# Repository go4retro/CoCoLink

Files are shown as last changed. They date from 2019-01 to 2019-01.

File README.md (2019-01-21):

# CoCoLink - A TANDY Color Computer RS-232 Pak Work-alike with High Speed mods and Sockmaster mods
This cartridge reproduces the functionality of the TANDY Color Computer RS-232 Pak with some performance enchancements.

## Enhancements
* Up to 4 cards are supported in a system ($ff68,$ff6c,$ff7x,$ff7c)
* Supports additional, faster bps rates, including 57,600 bps, 115,200 bps, and 230,400 bps
* Includes support for some of Sockmaster's [mods](http://users.axess.com/twilight/sock/rs232.html "mods"), including:
  * Swappable DCD and DSR lines
  * Auto-RTS (incomplete support at present)

## License
Copyright (C) 2018  RETRO Innovations

These files are free designs; you can redistribute them and/or modify
them under the terms of the Creative Commons Attribution-ShareAlike 
4.0 International License.

You should have received a copy of the license along with this
work. If not, see <http://creativecommons.org/licenses/by-sa/4.0/>.

These files are distributed in the hope that they will be useful,
but WITHOUT ANY WARRANTY; without even the implied warranty of
MERCHANTABILITY or FITNESS FOR A PARTICULAR PURPOSE.  See the
license for more details.

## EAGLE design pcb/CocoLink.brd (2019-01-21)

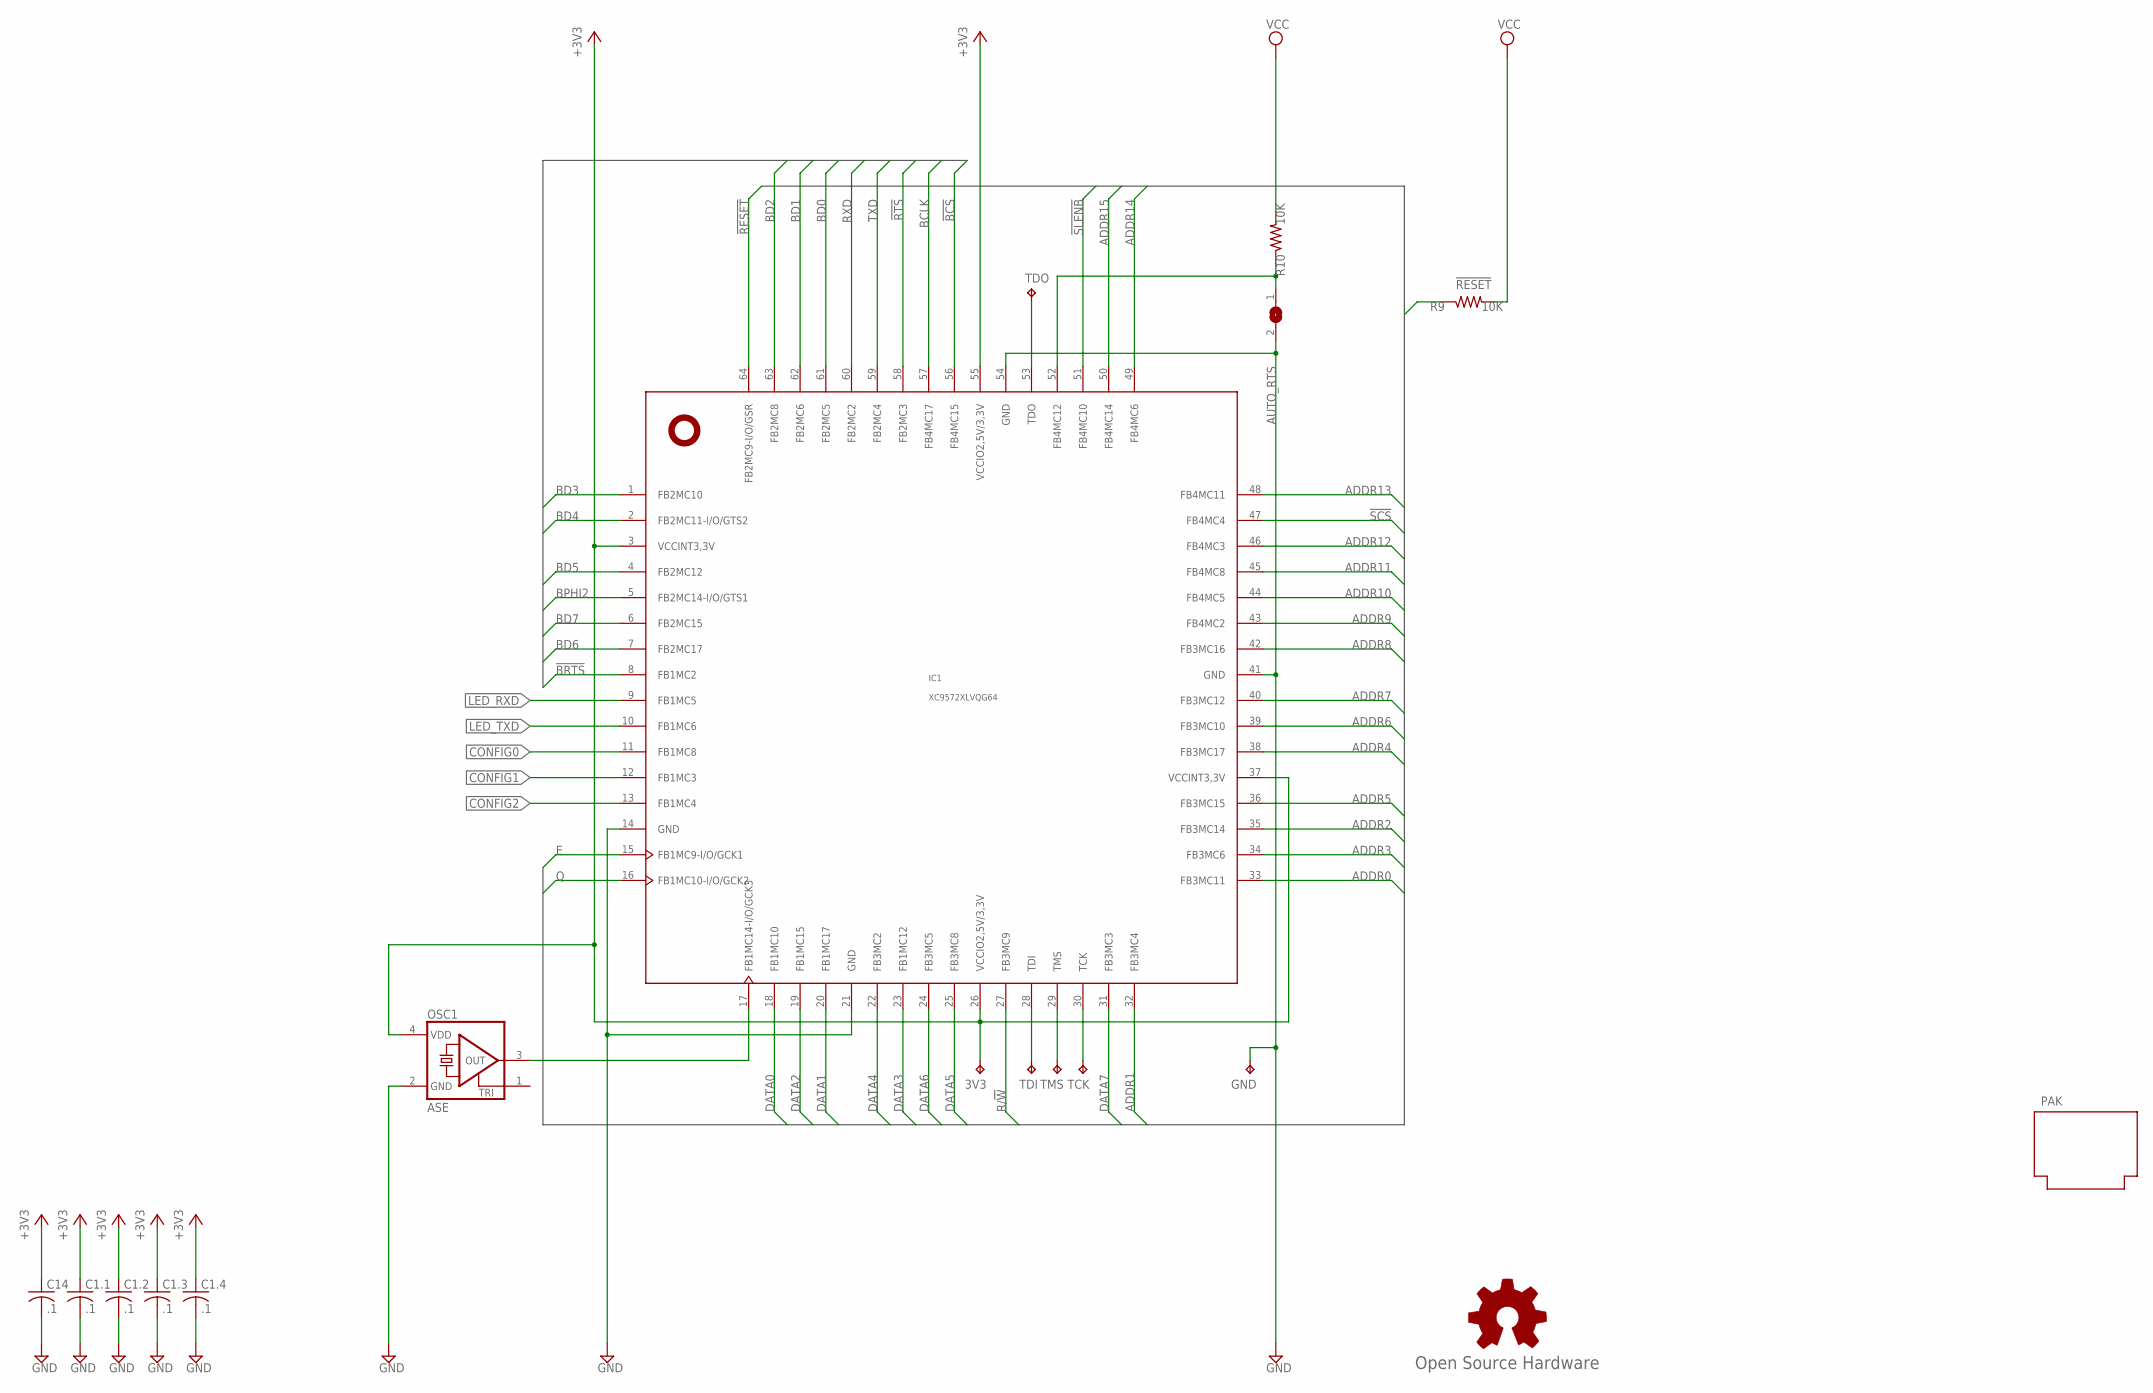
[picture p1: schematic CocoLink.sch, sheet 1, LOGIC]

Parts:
3V3: TPTP10R; TP10R
AUTO_RTS: SJ
C1.1, C1.2, C1.3, C1.4, C14: .1; C0402
GND: TPTP10R; TP10R
GOLD_ORB_SM1: Open Source Hardware; OSHW_8MM
IC1: XC9572XLVQG64; VQFP64
OSC1: ASE
PAK: PROGRAM_PAK
R9, R10: 10K; R0402
TCK: TPTP10R; TP10R
TDI: TPTP10R; TP10R
TDO: TPTP10R; TP10R
TMS: TPTP10R; TP10R

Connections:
!BCS: IC1.56 (FB4MC15); also elsewhere on the board
!BRTS: IC1.8 (FB1MC2); also elsewhere on the board
!RESET: IC1.64 (FB2MC9-I/O/GSR), R9.1; also elsewhere on the board
!RTS: IC1.58 (FB2MC3); also elsewhere on the board
!SCS: IC1.47 (FB4MC4); also elsewhere on the board
!SLENB: IC1.51 (FB4MC10); also elsewhere on the board
+3V3: 3V3.TP, C1.1.1, C1.2.1, C1.3.1, C1.4.1, C14.1, IC1.3 (VCCINT3,3V), IC1.26 (VCCIO2,5V/3,3V), IC1.37 (VCCINT3,3V), IC1.55 (VCCIO2,5V/3,3V), OSC1.4 (VDD); also elsewhere on the board
ADDR0: IC1.33 (FB3MC11); also elsewhere on the board
ADDR1: IC1.32 (FB3MC4); also elsewhere on the board
ADDR2: IC1.35 (FB3MC14); also elsewhere on the board
ADDR3: IC1.34 (FB3MC6); also elsewhere on the board
ADDR4: IC1.38 (FB3MC17); also elsewhere on the board
ADDR5: IC1.36 (FB3MC15); also elsewhere on the board
ADDR6: IC1.39 (FB3MC10); also elsewhere on the board
ADDR7: IC1.40 (FB3MC12); also elsewhere on the board
ADDR8: IC1.42 (FB3MC16); also elsewhere on the board
ADDR9: IC1.43 (FB4MC2); also elsewhere on the board
ADDR10: IC1.44 (FB4MC5); also elsewhere on the board
ADDR11: IC1.45 (FB4MC8); also elsewhere on the board
ADDR12: IC1.46 (FB4MC3); also elsewhere on the board
ADDR13: IC1.48 (FB4MC11); also elsewhere on the board
ADDR14: IC1.49 (FB4MC6); also elsewhere on the board
ADDR15: IC1.50 (FB4MC14); also elsewhere on the board
BCLK: IC1.57 (FB4MC17); also elsewhere on the board
BD0: IC1.61 (FB2MC5); also elsewhere on the board
BD1: IC1.62 (FB2MC6); also elsewhere on the board
BD2: IC1.63 (FB2MC8); also elsewhere on the board
BD3: IC1.1 (FB2MC10); also elsewhere on the board
BD4: IC1.2 (FB2MC11-I/O/GTS2); also elsewhere on the board
BD5: IC1.4 (FB2MC12); also elsewhere on the board
BD6: IC1.7 (FB2MC17); also elsewhere on the board
BD7: IC1.6 (FB2MC15); also elsewhere on the board
BPHI2: IC1.5 (FB2MC14-I/O/GTS1); also elsewhere on the board
CONFIG0: IC1.11 (FB1MC8); also elsewhere on the board
CONFIG1: IC1.12 (FB1MC3); also elsewhere on the board
CONFIG2: IC1.13 (FB1MC4); also elsewhere on the board
DATA0: IC1.18 (FB1MC10); also elsewhere on the board
DATA1: IC1.20 (FB1MC17); also elsewhere on the board
DATA2: IC1.19 (FB1MC15); also elsewhere on the board
DATA3: IC1.23 (FB1MC12); also elsewhere on the board
DATA4: IC1.22 (FB3MC2); also elsewhere on the board
DATA5: IC1.25 (FB3MC8); also elsewhere on the board
DATA6: IC1.24 (FB3MC5); also elsewhere on the board
DATA7: IC1.31 (FB3MC3); also elsewhere on the board
E: IC1.15 (FB1MC9-I/O/GCK1); also elsewhere on the board
GND: AUTO_RTS.2, C1.1.2, C1.2.2, C1.3.2, C1.4.2, C14.2, GND.TP, IC1.14 (GND), IC1.21 (GND), IC1.41 (GND), IC1.54 (GND), OSC1.2 (GND); also elsewhere on the board
LED_RXD: IC1.9 (FB1MC5); also elsewhere on the board
LED_TXD: IC1.10 (FB1MC6); also elsewhere on the board
unnamed: IC1.53 (TDO), TDO.TP
unnamed: IC1.28 (TDI), TDI.TP
unnamed: IC1.29 (TMS), TMS.TP
unnamed: IC1.30 (TCK), TCK.TP
unnamed: IC1.17 (FB1MC14-I/O/GCK3), OSC1.3 (OUT)
unnamed: AUTO_RTS.1, IC1.52 (FB4MC12), R10.1
Q: IC1.16 (FB1MC10-I/O/GCK2); also elsewhere on the board
R/!W: IC1.27 (FB3MC9); also elsewhere on the board
RXD: IC1.60 (FB2MC2); also elsewhere on the board
TXD: IC1.59 (FB2MC4); also elsewhere on the board
VCC: R9.2, R10.2; also elsewhere on the board

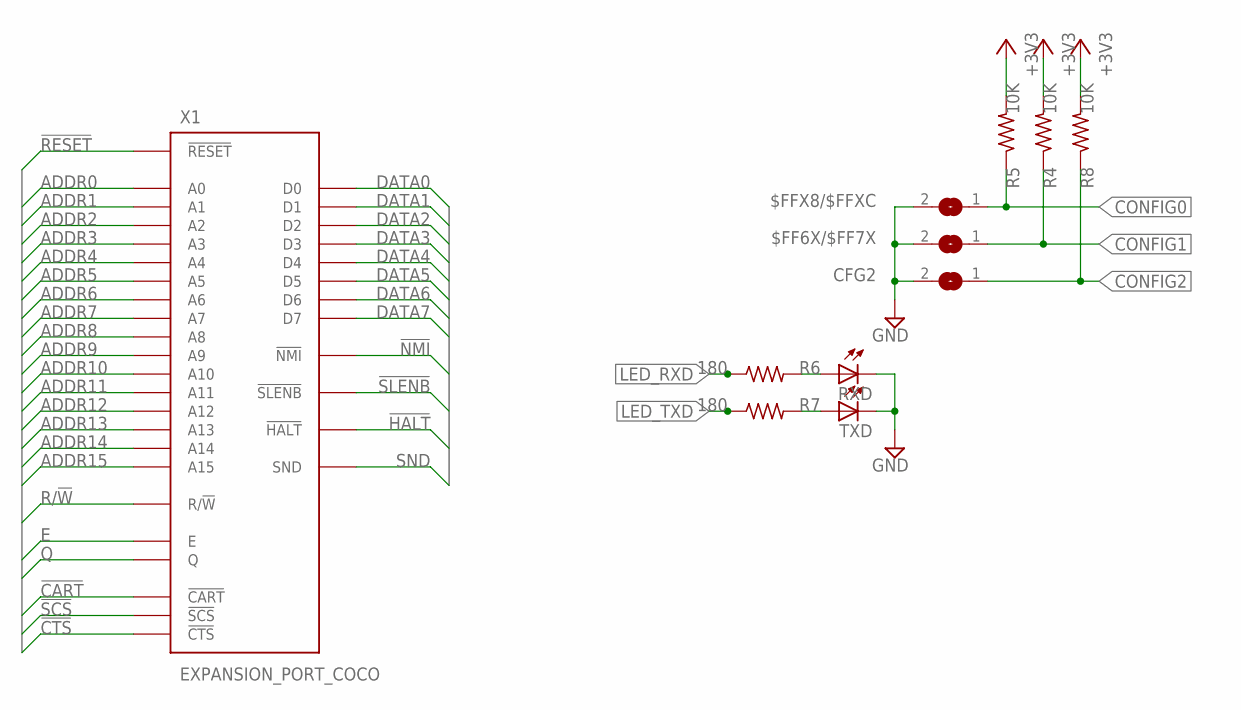
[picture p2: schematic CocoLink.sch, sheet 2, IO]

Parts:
$FF6X/$FF7X: SJ
$FFX8/$FFXC: SJ
CFG2: SJ
R4, R5, R8: 10K; R0402
R6, R7: 180; R0402
RXD: LED3MM
TXD: LED3MM
X1: EXPANSION_PORT_COCO; MA20-2

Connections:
!CART: X1.8 (!CART); also elsewhere on the board
!CTS: X1.32 (!CTS)
!HALT: X1.3 (!HALT)
!NMI: X1.4 (!NMI)
!RESET: X1.5 (!RESET); also elsewhere on the board
!SCS: X1.36 (!SCS); also elsewhere on the board
!SLENB: X1.40 (!SLENB); also elsewhere on the board
+3V3: R4.2, R5.2, R8.2; also elsewhere on the board
+12V: X1.2 (+12V)
-12V: X1.1 (-12V)
ADDR0: X1.19 (A0); also elsewhere on the board
ADDR1: X1.20 (A1); also elsewhere on the board
ADDR2: X1.21 (A2); also elsewhere on the board
ADDR3: X1.22 (A3); also elsewhere on the board
ADDR4: X1.23 (A4); also elsewhere on the board
ADDR5: X1.24 (A5); also elsewhere on the board
ADDR6: X1.25 (A6); also elsewhere on the board
ADDR7: X1.26 (A7); also elsewhere on the board
ADDR8: X1.27 (A8); also elsewhere on the board
ADDR9: X1.28 (A9); also elsewhere on the board
ADDR10: X1.29 (A10); also elsewhere on the board
ADDR11: X1.30 (A11); also elsewhere on the board
ADDR12: X1.31 (A12); also elsewhere on the board
ADDR13: X1.37 (A13); also elsewhere on the board
ADDR14: X1.38 (A14); also elsewhere on the board
ADDR15: X1.39 (A15); also elsewhere on the board
CONFIG0: $FFX8/$FFXC.1, R5.1; also elsewhere on the board
CONFIG1: $FF6X/$FF7X.1, R4.1; also elsewhere on the board
CONFIG2: CFG2.1, R8.1; also elsewhere on the board
DATA0: X1.10 (D0); also elsewhere on the board
DATA1: X1.11 (D1); also elsewhere on the board
DATA2: X1.12 (D2); also elsewhere on the board
DATA3: X1.13 (D3); also elsewhere on the board
DATA4: X1.14 (D4); also elsewhere on the board
DATA5: X1.15 (D5); also elsewhere on the board
DATA6: X1.16 (D6); also elsewhere on the board
DATA7: X1.17 (D7); also elsewhere on the board
E: X1.6 (E); also elsewhere on the board
GND: $FF6X/$FF7X.2, $FFX8/$FFXC.2, CFG2.2, RXD.K (C), TXD.K (C), X1.33 (GND), X1.34 (GND); also elsewhere on the board
LED_RXD: R6.1; also elsewhere on the board
LED_TXD: R7.1; also elsewhere on the board
unnamed: R7.2, TXD.A
unnamed: R6.2, RXD.A
Q: X1.7 (Q); also elsewhere on the board
R/!W: X1.18 (R/!W); also elsewhere on the board
SND: X1.35 (SND)
VCC: X1.9 (VCC); also elsewhere on the board

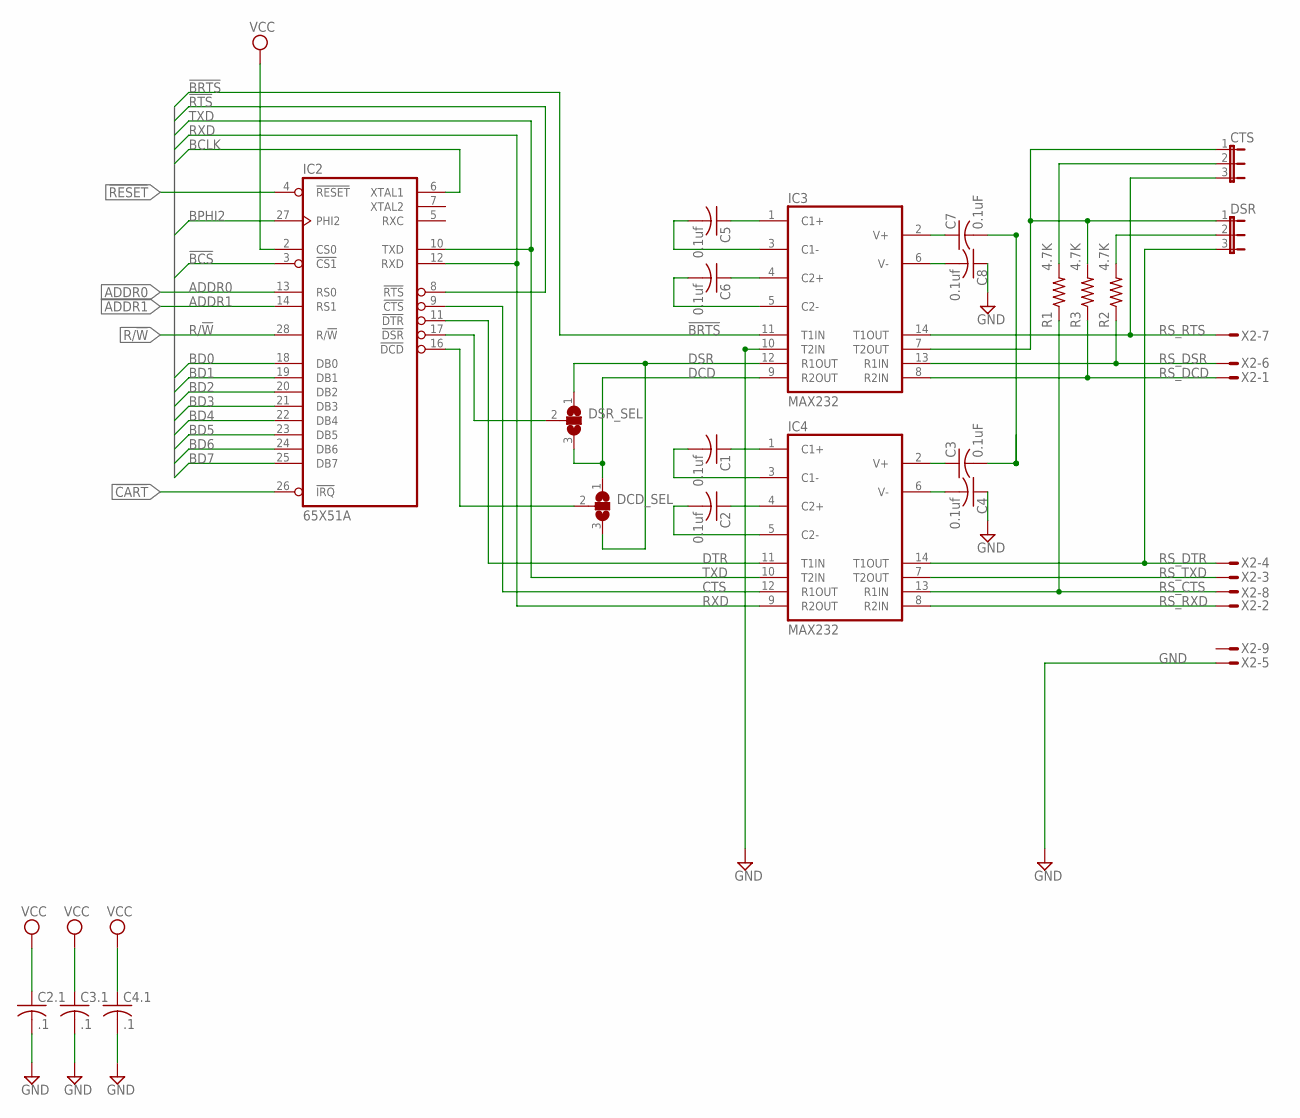
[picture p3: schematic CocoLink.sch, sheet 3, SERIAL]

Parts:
C1, C2, C4, C5, C6, C8: 0.1uf; C0402
C2.1, C3.1, C4.1: .1; C0402
C3, C7: 0.1uF; C0402
CTS: JP2E; JP2
DCD_SEL: SJ2W; SJ_2
DSR: JP2E; JP2
DSR_SEL: SJ2W; SJ_2
IC2: 65X51A; DIL28-ROUNDPAD
IC3, IC4: MAX232; SO16
R1, R2, R3: 4.7K; R1206
X2: M09DS; M09D

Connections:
!BCS: IC2.3 (!CS1); also elsewhere on the board
!BRTS: IC3.11 (T1IN); also elsewhere on the board
!CART: IC2.26 (!IRQ); also elsewhere on the board
!RESET: IC2.4 (!RESET); also elsewhere on the board
!RTS: IC2.8 (!RTS); also elsewhere on the board
ACIA_DCD: DCD_SEL.2, IC2.16 (!DCD)
ACIA_DSR: DSR_SEL.2, IC2.17 (!DSR)
ADDR0: IC2.13 (RS0); also elsewhere on the board
ADDR1: IC2.14 (RS1); also elsewhere on the board
BCLK: IC2.6 (XTAL1); also elsewhere on the board
BD0: IC2.18 (DB0); also elsewhere on the board
BD1: IC2.19 (DB1); also elsewhere on the board
BD2: IC2.20 (DB2); also elsewhere on the board
BD3: IC2.21 (DB3); also elsewhere on the board
BD4: IC2.22 (DB4); also elsewhere on the board
BD5: IC2.23 (DB5); also elsewhere on the board
BD6: IC2.24 (DB6); also elsewhere on the board
BD7: IC2.25 (DB7); also elsewhere on the board
BPHI2: IC2.27 (PHI2); also elsewhere on the board
CTS: IC2.9 (!CTS), IC4.12 (R1OUT)
DCD: DCD_SEL.1, DSR_SEL.3, IC3.9 (R2OUT)
DSR: DCD_SEL.3, DSR_SEL.1, IC3.12 (R1OUT)
DTR: IC2.11 (!DTR), IC4.11 (T1IN)
GND: C2.1.2, C3.1.2, C4.1, C4.1.2, C8.1, IC2.1 (GND), IC3.10 (T2IN), IC3.15 (GND), IC4.15 (GND), X2.5; also elsewhere on the board
unnamed: DSR.2, R2.2
unnamed: CTS.1, DSR.1, IC3.7 (T2OUT), R3.2
unnamed: CTS.2, R1.2
unnamed: C1.1, IC4.1 (C1+)
unnamed: C1.2, IC4.3 (C1-)
unnamed: C2.1, IC4.4 (C2+)
unnamed: C2.2, IC4.5 (C2-)
unnamed: C3.1, IC4.2 (V+)
unnamed: C4.2, IC4.6 (V-)
unnamed: C5.1, IC3.1 (C1+)
unnamed: C5.2, IC3.3 (C1-)
unnamed: C6.1, IC3.4 (C2+)
unnamed: C6.2, IC3.5 (C2-)
unnamed: C7.1, IC3.2 (V+)
unnamed: C8.2, IC3.6 (V-)
R/!W: IC2.28 (R/!W); also elsewhere on the board
RS_CTS: IC4.13 (R1IN), R1.1, X2.8
RS_DCD: IC3.13 (R1IN), R2.1, X2.6
RS_DSR: IC3.8 (R2IN), R3.1, X2.1
RS_DTR: DSR.3, IC4.14 (T1OUT), X2.4
RS_RTS: CTS.3, IC3.14 (T1OUT), X2.7
RS_RXD: IC4.8 (R2IN), X2.2
RS_TXD: IC4.7 (T2OUT), X2.3
RXD: IC2.12 (RXD), IC4.9 (R2OUT); also elsewhere on the board
TXD: IC2.10 (TXD), IC4.10 (T2IN); also elsewhere on the board
VCC: C2.1.1, C3.2, C3.1.1, C4.1.1, C7.2, IC2.2 (CS0), IC2.15 (VCC), IC3.16 (VCC), IC4.16 (VCC); also elsewhere on the board

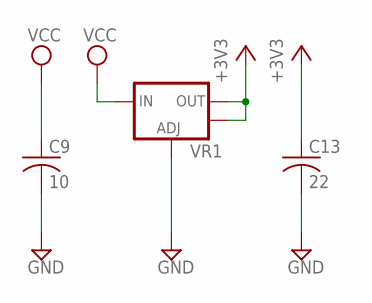
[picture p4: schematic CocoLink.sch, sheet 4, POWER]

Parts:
C9: 10; C0805
C13: 22; C0805
VR1: V_REG_LM1117SOT223; SOT223

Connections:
+3V3: C13.1, VR1.2 (OUT), VR1.4 (OUT); also elsewhere on the board
GND: C9.2, C13.2, VR1.1 (ADJ); also elsewhere on the board
VCC: C9.1, VR1.3 (IN); also elsewhere on the board

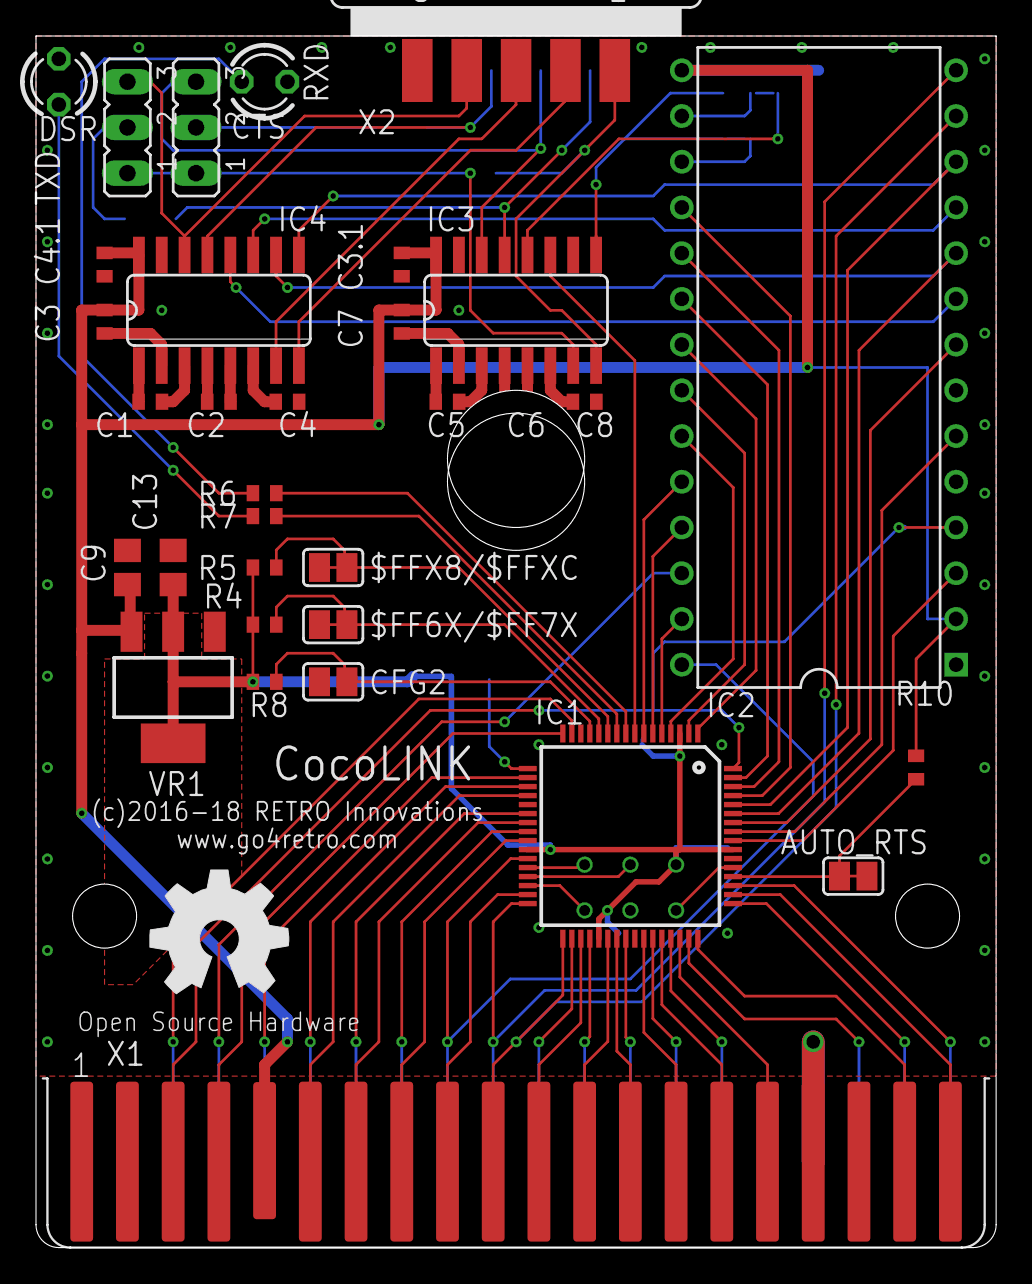
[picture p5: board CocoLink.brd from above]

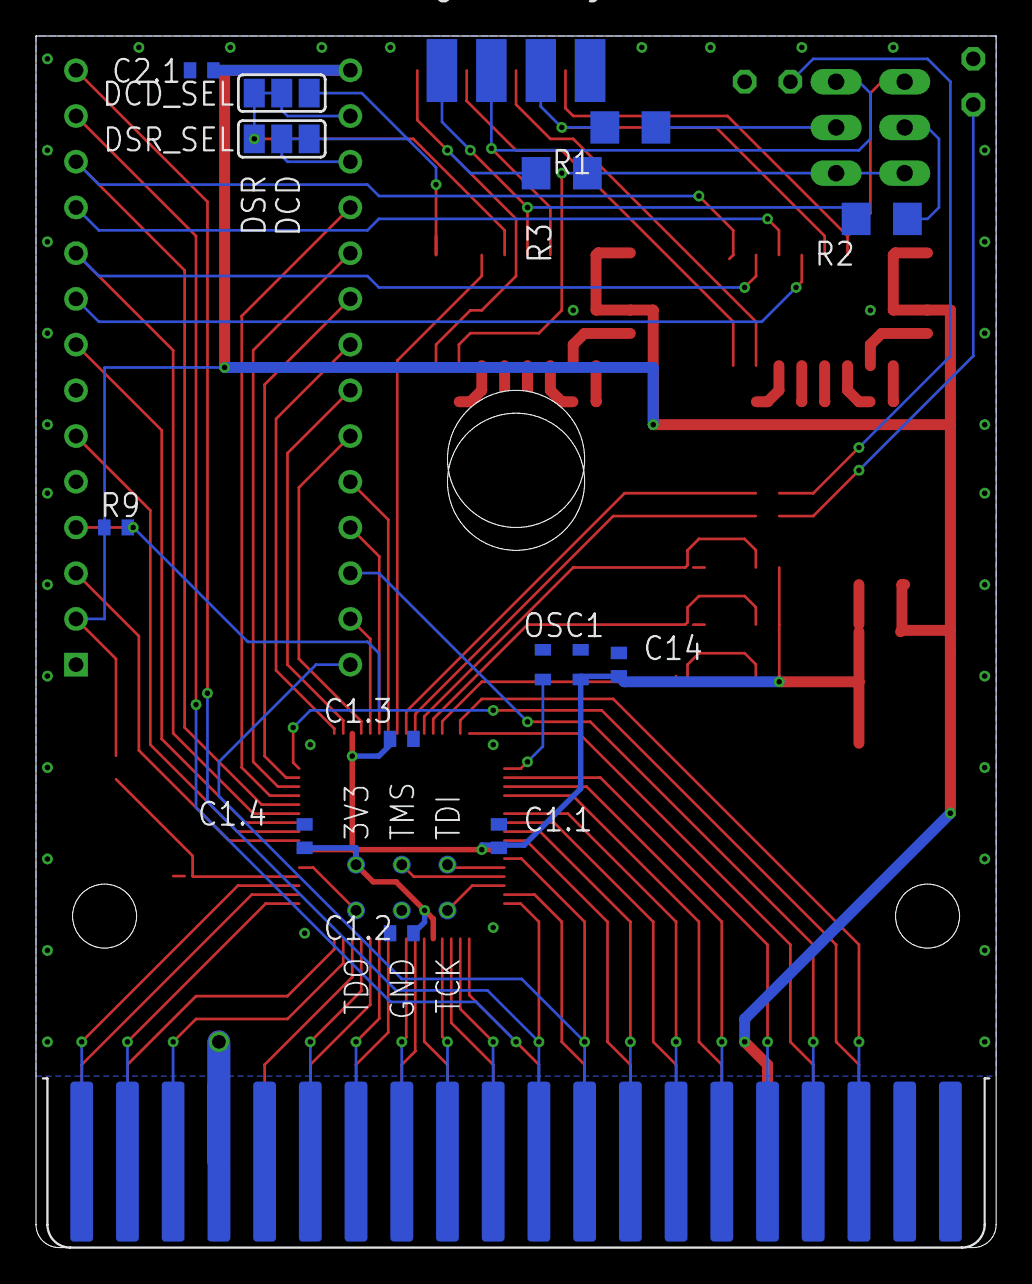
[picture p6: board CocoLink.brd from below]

Board: 2 copper layers, 53.3 x 67.3 mm, 54 parts (19 on the bottom side), 90 nets.

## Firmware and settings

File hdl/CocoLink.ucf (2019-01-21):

#PACE: Start of Constraints generated by PACE

#PACE: Start of PACE I/O Pin Assignments
NET "_acia_ce"  LOC = "P56"  ; 
NET "_reset"  LOC = "P64"  ; 
NET "_slenb"  LOC = "P51"  ; 
NET "acia_clock_in"  LOC = "P17"  ; 
NET "acia_clock_out"  LOC = "P57"  ; 
NET "acia_data<0>"  LOC = "P61"  ; 
NET "acia_data<1>"  LOC = "P62"  ; 
NET "acia_data<2>"  LOC = "P63"  ; 
NET "acia_data<3>"  LOC = "P1"  ; 
NET "acia_data<4>"  LOC = "P2"  ; 
NET "acia_data<5>"  LOC = "P4"  ; 
NET "acia_data<6>"  LOC = "P7"  ; 
NET "acia_data<7>"  LOC = "P6"  ; 
NET "acia_phi2"  LOC = "P5"  ; 
NET "acia_rts"  LOC = "P58"  ;
NET "acia_rxd"  LOC = "P60"  ; 
NET "acia_txd"  LOC = "P59"  ; 
NET "address<0>"  LOC = "P33"  ; 
NET "address<10>"  LOC = "P44"  ; 
NET "address<11>"  LOC = "P45"  ; 
NET "address<12>"  LOC = "P46"  ; 
NET "address<13>"  LOC = "P48"  ; 
NET "address<14>"  LOC = "P49"  ; 
NET "address<15>"  LOC = "P50"  ; 
NET "address<1>"  LOC = "P32"  ; 
NET "address<2>"  LOC = "P35"  ; 
NET "address<3>"  LOC = "P34"  ; 
NET "address<4>"  LOC = "P38"  ; 
NET "address<5>"  LOC = "P36"  ; 
NET "address<6>"  LOC = "P39"  ; 
NET "address<7>"  LOC = "P40"  ; 
NET "address<8>"  LOC = "P42"  ; 
NET "address<9>"  LOC = "P43"  ; 
NET "cfg<0>"  LOC = "P11"  ; 
NET "cfg<1>"  LOC = "P12"  ; 
NET "data<0>"  LOC = "P18"  ; 
NET "data<1>"  LOC = "P20"  ; 
NET "data<2>"  LOC = "P19"  ; 
NET "data<3>"  LOC = "P23"  ; 
NET "data<4>"  LOC = "P22"  ; 
NET "data<5>"  LOC = "P25"  ; 
NET "data<6>"  LOC = "P24"  ; 
NET "data<7>"  LOC = "P31"  ; 
NET "e"  LOC = "P15"  ; 
NET "led_rxd"  LOC = "P9"  ; 
NET "led_txd"  LOC = "P10"  ; 
NET "r_w"  LOC = "P27"  ; 
NET "rs_rts"  LOC = "P8"  ;

#PACE: Start of PACE Area Constraints

#PACE: Start of PACE Prohibit Constraints

#PACE: End of Constraints generated by PACE

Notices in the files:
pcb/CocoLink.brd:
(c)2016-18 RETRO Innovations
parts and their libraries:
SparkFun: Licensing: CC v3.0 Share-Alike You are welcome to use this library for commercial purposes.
